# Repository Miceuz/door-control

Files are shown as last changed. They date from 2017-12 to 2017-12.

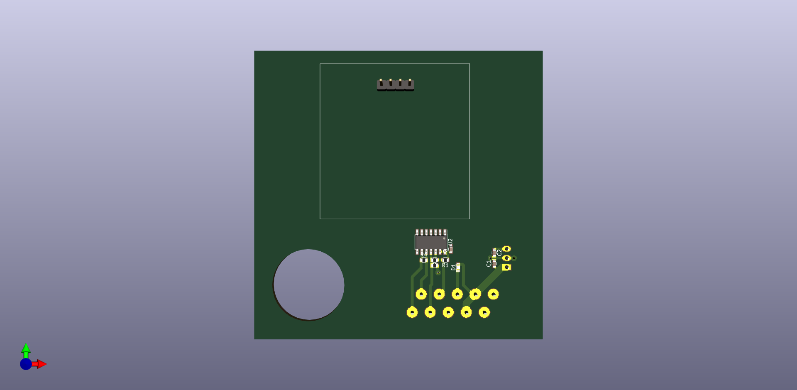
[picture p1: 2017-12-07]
scanner/scanner.png

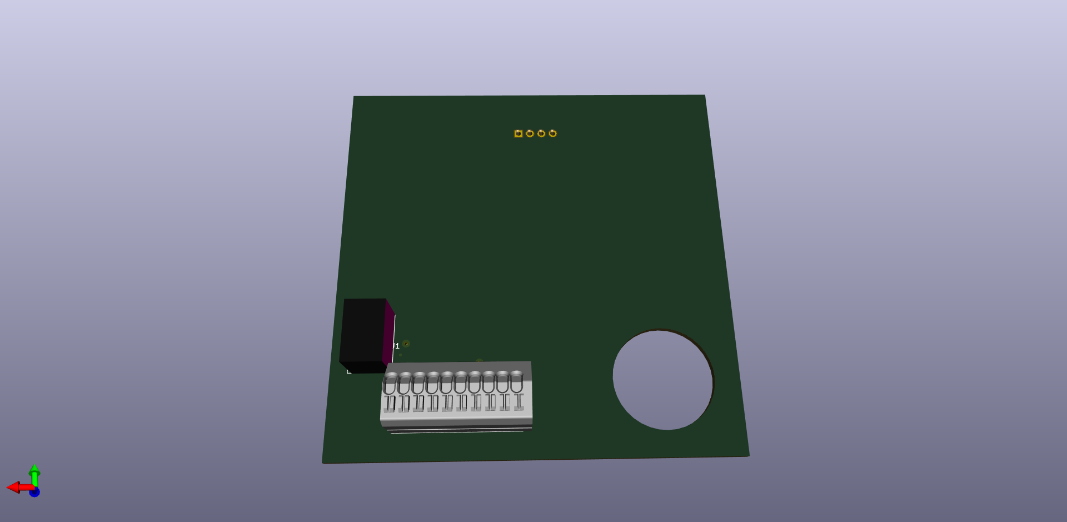
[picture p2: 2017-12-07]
scanner/scanner-back.png

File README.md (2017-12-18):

# door-control
An entrance to hackerspace control system

randominis minčių kratinys

 * Du maitinimo blokai - vienas, 5V maitina ESP32 plokštę, kitas, 12V - "purvinąją" pusę
 X* Iš 5V patempti už kojos tranzistorių ir sekti, ar yra 5V maitinimas
 X* Iš 12V per optoporą patempti tranzistorių ir sekti, ar yra 12V maitinimas
 X* RS485 izoliuotas per AD2482/AD2487
 * Išlituoti barrel lizdą įlituoti screw term
 http://www.mouser.com/pdfdocs/Bourns_RS485_AppNote.pdf

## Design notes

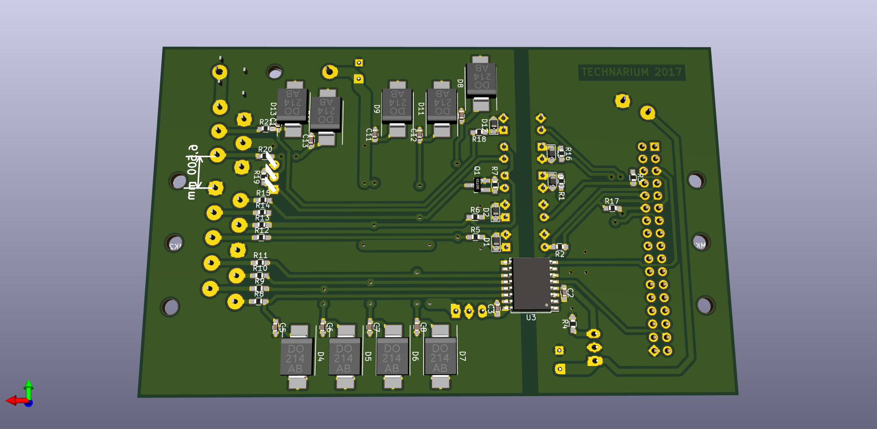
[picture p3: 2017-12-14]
controller2/controller2-bot.png

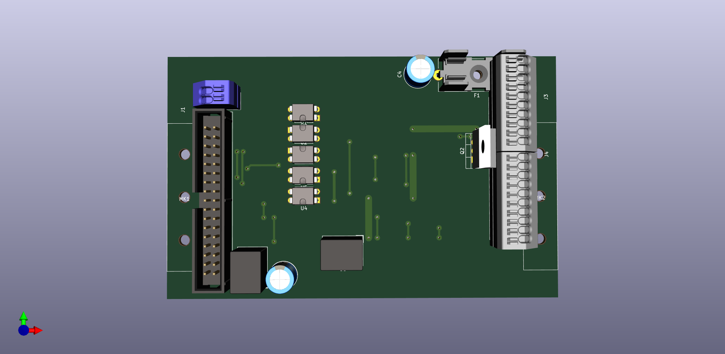
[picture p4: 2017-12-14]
controller2/controller2-top.png

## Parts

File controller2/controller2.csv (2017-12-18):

Reference | Quantity | Value | Footprint | PartNo | Manufacturer | Distributor
C1 C4 | 2 | CP | Capacitors_THT:CP_Radial_D8.0mm_P3.50mm | EEUFR1J151L | PANASONIC | 2760345
C10 C11 C12 C13 C2 C3 C5 C6 C7 C8 C9 | 11 | C | Capacitors_SMD:C_0603_HandSoldering |  |  | xxx
D11 D13 D14 D4 D5 D6 D7 D8 D9 | 9 | SMCJ24CA | Diodes_SMD:DO-214AB_Handsoldering | SMCJ24CA | LITTLEFUSE | 2762835
D1 D10 D12 D2 D3 | 5 | D_Small | Diodes_SMD:D_SOD-323_HandSoldering | 1N4148 | MULTICOMP | 1466524
F1 | 1 | Fuse | Fuse_Holders_and_Fuses:Fuseholder5x20_horiz_open_Schurter_0031_8201 | 0031.8201 | SCHURTER | 1162740
J1 | 1 | 5V_IN | door:TerminalBlock_WAGO-205_2pol | 250-402 | WAGO | 1891588
J2 | 1 | Conn_02x17_Odd_Even | Connectors_IDC:IDC-Header_2x17_Pitch2.54mm_Straight | T821134A1S100CEU | AMPHENOL | 2215313
J3 | 1 | Conn_01x06 | door:TerminalBlock_WAGO-205_10pol | 250-406 | WAGO | 1891592
J4 | 1 | Conn_01x10 | door:TerminalBlock_WAGO-205_10pol | 250-410 | WAGO | 1891594
Q1 | 1 | Q_NMOS_GSD | Housings_SOT-23_SOT-143_TSOT-6:SOT-23_Handsoldering | TN2404K-T1-GE3 | VISHAY | 2295731
Q2 | 1 | Q_NMOS_GSD | TO_SOT_Packages_THT:TO-220-3_Vertical | IRLZ14PBF | VISHAY | 8651370
R1 R16 R17 R18 R19 R2 R3 R4 R5 R6 R7 | 11 | R | Resistors_SMD:R_0603_HandSoldering |  |  | xxxx
R10 R11 R12 R13 R14 R15 R20 R21 R8 R9 | 10 | R_Small | Resistors_SMD:R_0603_HandSoldering | ERJPA3F10R0V | PANASONIC | 2335834
U1 U6 | 2 | R-78E3.3-0.5 | Converters_DCDC_ACDC:DCDC-Conv_RECOM_R-78E-0.5 | R-78E3.3-0.5 | RECOM | 2218602
U3 | 1 | ADM2482 | Housings_SOIC:SOIC-16W_7.5x10.3mm_Pitch1.27mm | ADM2487EBRWZ | ANALOG DEVICES | 2758680
U2 U4 U5 U7 U8 | 5 | TLP222 |  | TLP222A | TOSHIBA | 1761595

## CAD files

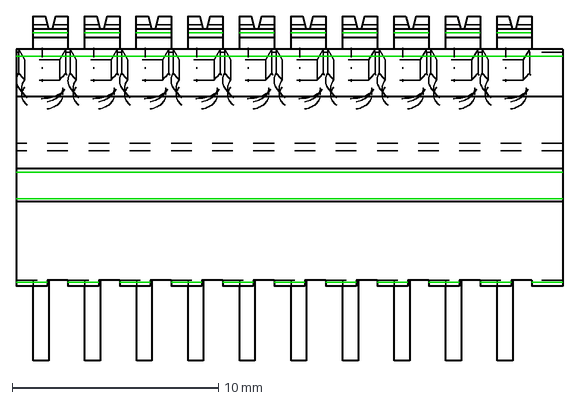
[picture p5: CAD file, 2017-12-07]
3d/250-410_left.dxf
26.5 x 16.7 mm

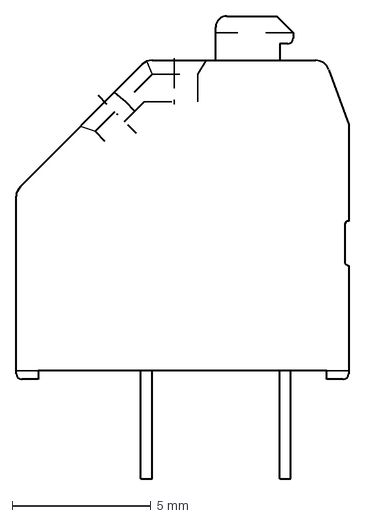
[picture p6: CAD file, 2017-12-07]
3d/250-410_back.dxf
12.0 x 16.7 mm

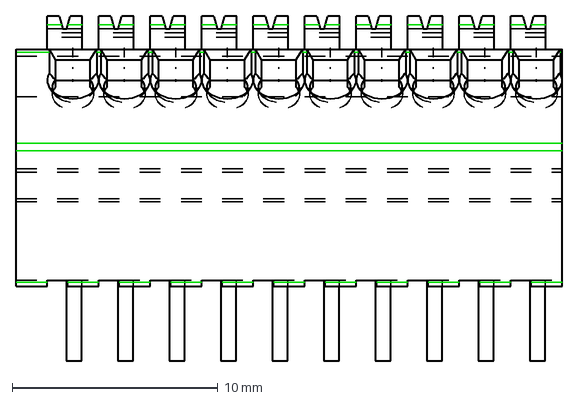
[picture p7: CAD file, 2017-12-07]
3d/250-410_right.dxf
26.6 x 16.7 mm

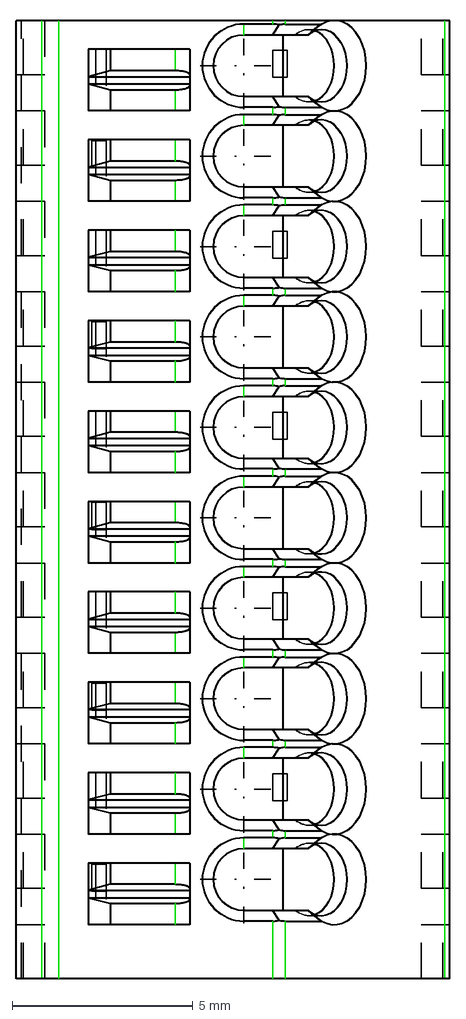
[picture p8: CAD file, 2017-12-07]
3d/250-410_top.dxf
12.0 x 26.6 mm

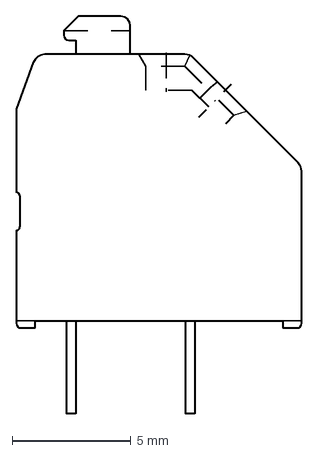
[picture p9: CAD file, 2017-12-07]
3d/250-410_front.dxf
12.0 x 16.7 mm

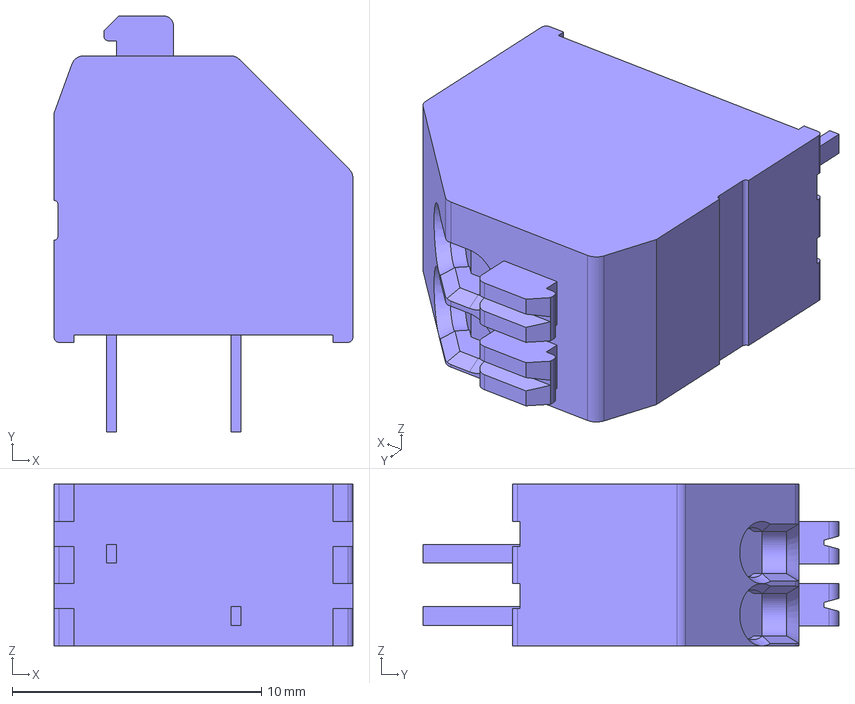
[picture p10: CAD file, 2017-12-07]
3d/250-402_000-006.stp
12.0 x 16.7 x 6.50 mm

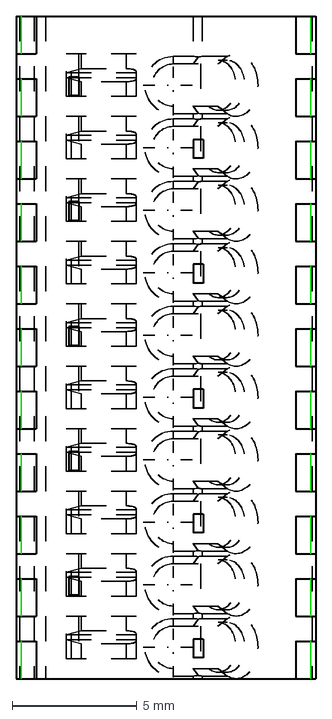
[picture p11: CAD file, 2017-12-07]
3d/250-410_bottom.dxf
12.0 x 26.5 mm

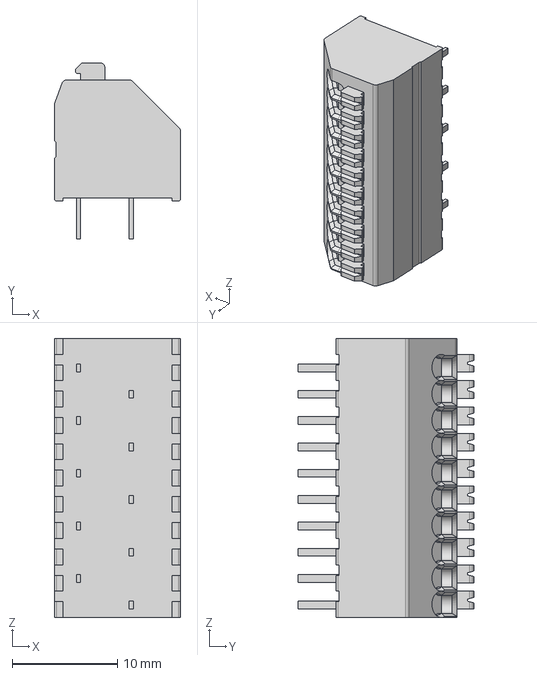
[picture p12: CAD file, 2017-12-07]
3d/250-410.stp
12.0 x 16.7 x 26.5 mm

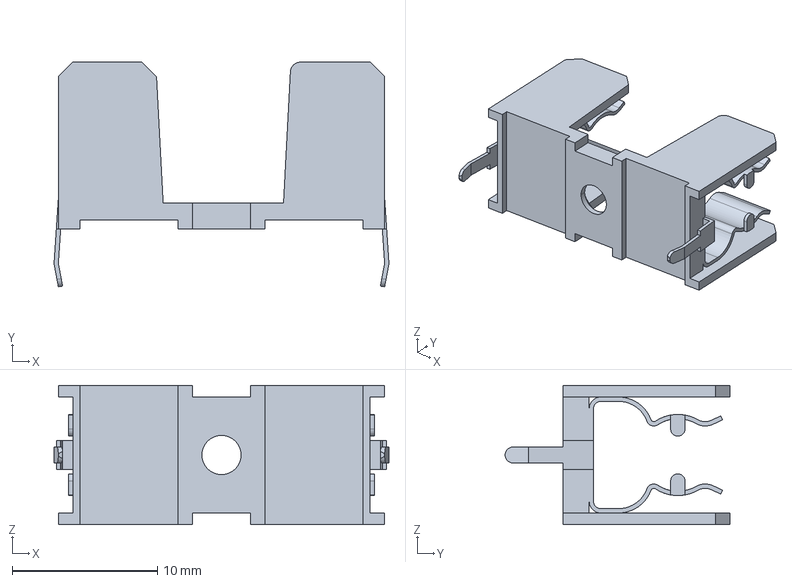
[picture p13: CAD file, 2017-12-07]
3d/31-8201.stp
23.1 x 15.5 x 9.60 mm

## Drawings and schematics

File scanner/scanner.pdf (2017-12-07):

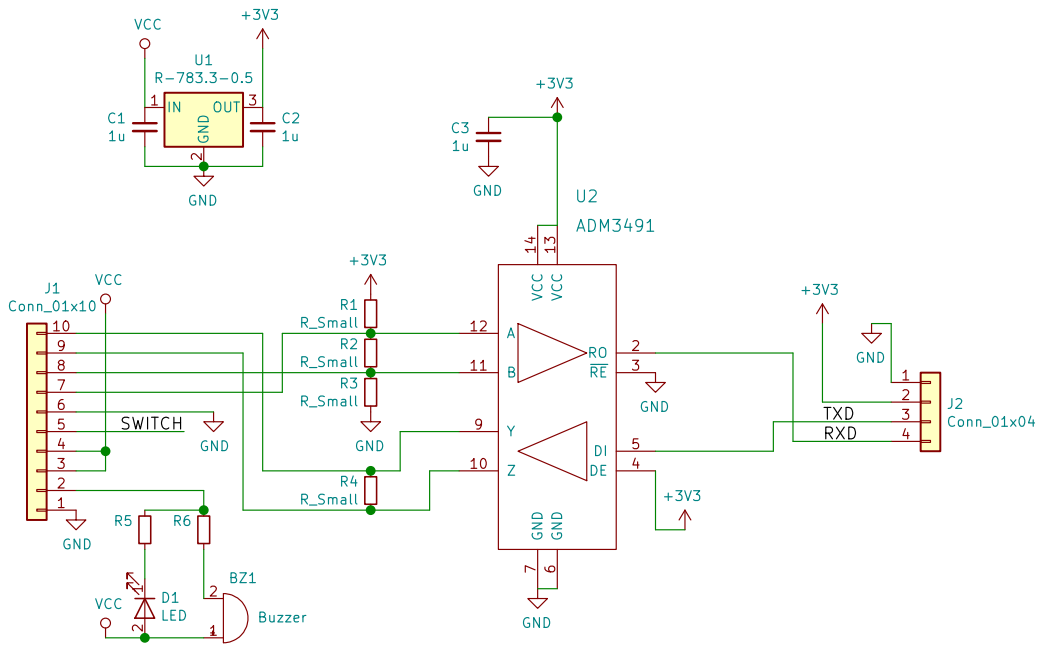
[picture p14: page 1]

RXD 4

Id: 1/1 Title: File: scanner.sch Sheet: / Albertas Micknas

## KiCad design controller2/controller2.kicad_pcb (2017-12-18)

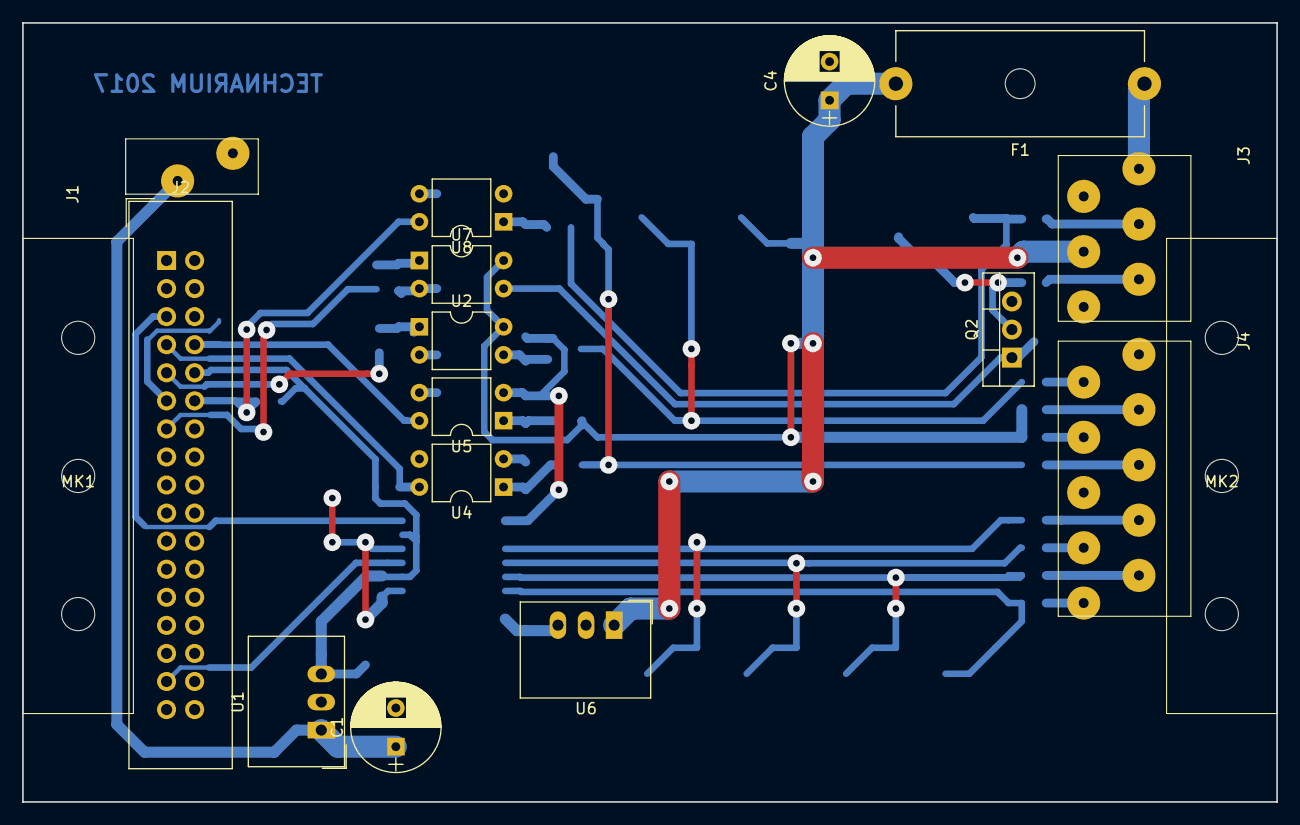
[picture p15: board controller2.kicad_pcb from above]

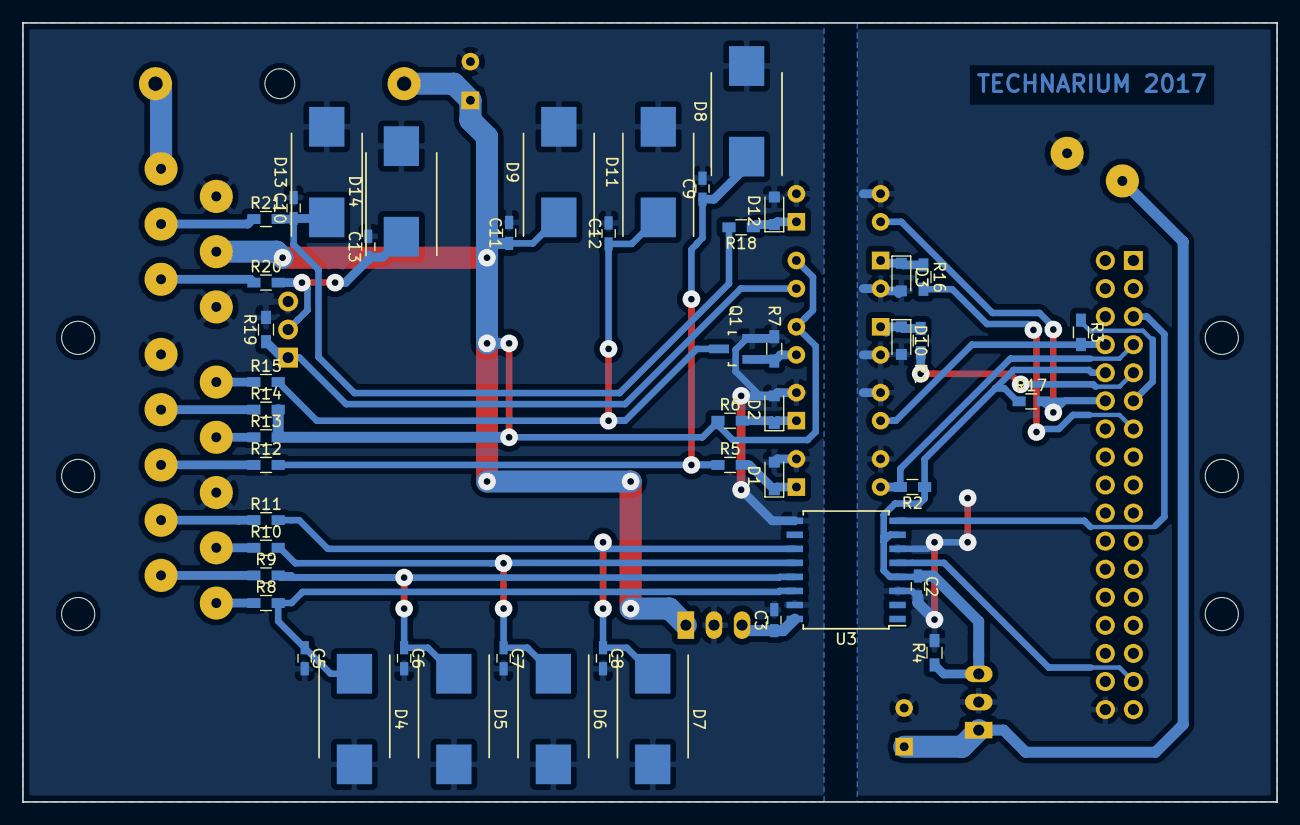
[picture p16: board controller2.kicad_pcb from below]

Board: 2 copper layers, 113.5 x 70.5 mm, 65 parts (48 on the bottom side), 40 nets.

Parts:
C1, C4: CP; CP_Radial_D8.0mm_P3.50mm
C2, C3, C5, C6, C7, C8, C9, C10, C11, C12, C13: C; C_0603_HandSoldering
D1, D2, D3, D10, D12: D_Small; D_SOD-323_HandSoldering
D4, D5, D6, D7, D8, D9, D11, D13, D14: SMCJ12CA; DO-214AB_Handsoldering
F1: Fuse; Fuseholder5x20_horiz_open_Schurter_0031_8201
J1: 5V_IN; TerminalBlock_WAGO-205_2pol
J2: Conn_02x17_Odd_Even; IDC-Header_2x17_Pitch2.54mm_Straight
J3: Conn_01x06; TerminalBlock_WAGO-205_10pol
J4: Conn_01x10; TerminalBlock_WAGO-205_10pol
MK1, MK2: Mounting_Hole; DIN_CLIP
Q1: Q_NMOS_GSD; SOT-23_Handsoldering
Q2: Q_NMOS_GSD; TO-220-3_Vertical
R1, R2, R3, R4, R5, R6, R7, R16, R17, R18, R19: R; R_0603_HandSoldering
R8, R9, R10, R11, R12, R13, R14, R15, R20, R21: R_Small; R_0603_HandSoldering
U1, U6: R-78E3.3-0.5; DCDC-Conv_RECOM_R-78E-0.5
U2, U4, U5, U7, U8: TLP222A; DIP-4_W7.62mm
U3: ADM2482; SOIC-16W_7.5x10.3mm_Pitch1.27mm

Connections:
+3V3: C2.1, J2.10, R2.1, R4.1, R17.1, U1.3, U3.4, U3.7
/AUX_IN: C10.1, D13.1, R18.2, R21.2
/AUX_IN_ISO: J2.12, R17.2, U8.4
/AUX_OUT: C13.1, D14.1, Q2.2, R20.2
/AUX_OUT_ISO: J2.13, R16.2
/BUZZ_ISO: J2.9, R1.2
/BUZZ_LED: C12.1, D11.1, Q1.3, R15.2
/RxD: J2.31, U3.5
/SWITCH: C9.1, D8.1, R5.1, R12.2
/TxD: J2.5, U3.8
/VCC_TEST: J2.11, R3.1
/~SWITCH_ISO: J2.7, R2.2, U4.4
/~VCC_GOOD: J2.8, R3.2, U5.4
GND: C1.2, C2.2, D3.2, D10.2, J1.2, J2.34, R4.2, U1.2, U2.2, U3.3, U3.6, U4.3, U5.3, U7.2, U8.3
GNDD: C3.2, C4.2, C5.2, C6.2, C7.2, C8.2, C9.2, C10.2, C11.2, C12.2, C13.2, D1.2, D2.2, D4.2, D5.2, D6.2, D7.2, D8.2, D9.2, D11.2, D12.2, D13.2, D14.2, J3.2, J3.6, J4.1, J4.6, Q1.2, Q2.3, R7.2, R19.2, U3.9, U3.15, U4.2, U5.2, U6.2, U8.2
unnamed: C1.1, J1.1, U1.1
unnamed: C3.1, U3.16, U6.3
unnamed: C5.1, D4.1, R8.2, U3.14
unnamed: C6.1, D5.1, R9.2, U3.13
unnamed: C7.1, D6.1, R10.2, U3.12
unnamed: C8.1, D7.1, R11.2, U3.11
unnamed: D1.1, R5.2, U4.1
unnamed: D2.1, R6.2, U5.1
unnamed: D3.1, R16.1, U7.1
unnamed: D10.1, R1.1, U2.1
unnamed: D12.1, R18.1, U8.1
unnamed: F1.1, J3.1
unnamed: J3.3, R21.1
unnamed: J3.5, R20.1
unnamed: J4.2, R15.1
unnamed: J4.3, R14.1
unnamed: J4.4, R13.1
unnamed: J4.5, R12.1
unnamed: J4.7, R11.1
unnamed: J4.8, R10.1
unnamed: J4.9, R9.1
unnamed: J4.10, R8.1
unnamed: Q1.1, R7.1, U2.3
unnamed: Q2.1, R19.1, U7.3
VCC: C4.1, C11.1, D9.1, F1.2, J3.4, R6.1, R13.2, R14.2, U2.4, U6.1, U7.4

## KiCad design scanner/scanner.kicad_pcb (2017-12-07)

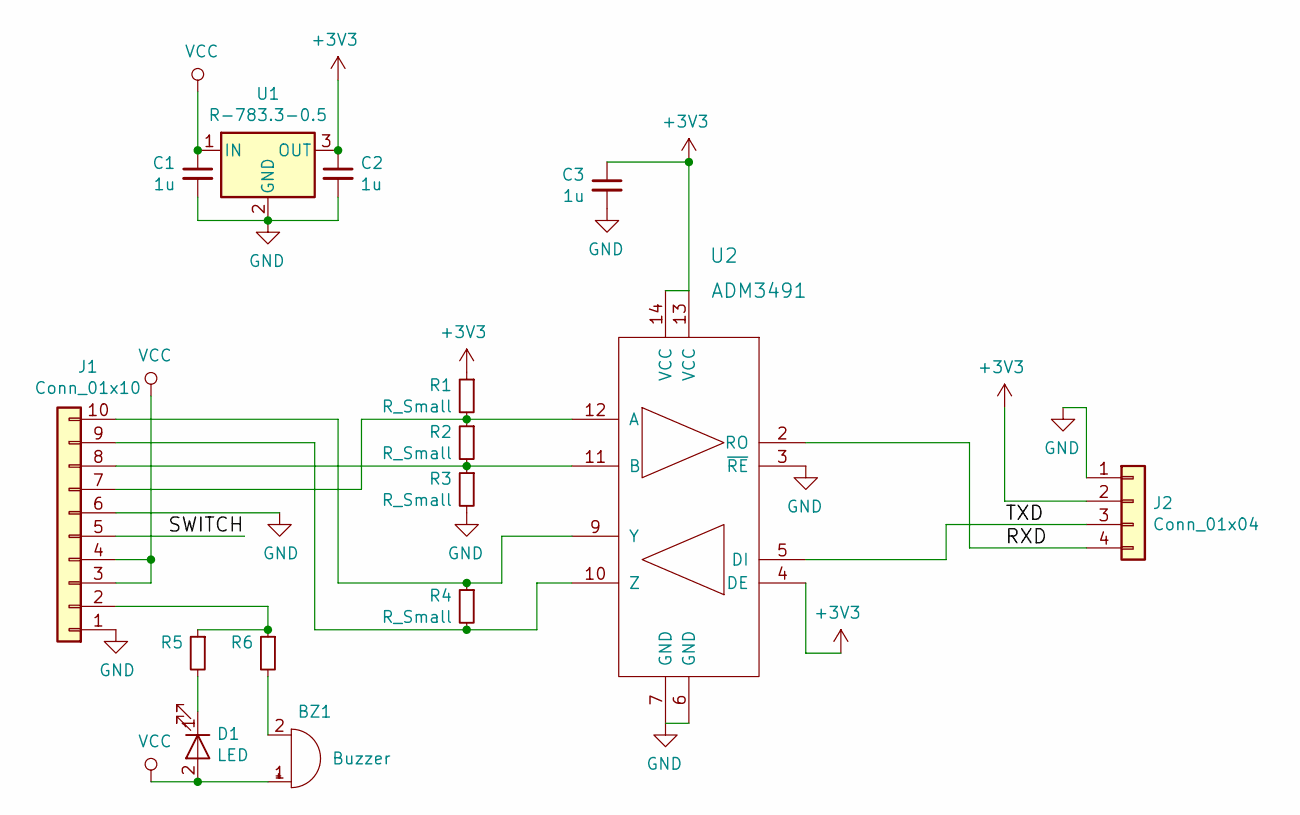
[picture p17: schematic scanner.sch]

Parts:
BZ1: Buzzer; Buzzer_12x9.5RM7.6; PartNo AI-1440-TWT-12V-R
C1, C2, C3: 1u; C_0603; PartNo ?
D1: LED; LED_0603; PartNo ?
J1: Conn_01x10; TerminalBlock_WAGO-804_RM5mm_10pol; PartNo 250-410
J2: Conn_01x04; Pin_Header_Straight_1x04_Pitch2.54mm; PartNo ?
R1, R2, R3, R4: R_Small; R_0603; PartNo ?
R5, R6: R_0603; PartNo ?
U1: R-783.3-0.5; DCDC-Conv_RECOM_R-78E-0.5; PartNo R-78E3.3-0.5
U2: ADM3491; SOIC-14_3.9x8.7mm_Pitch1.27mm; PartNo ADM3491EARZ

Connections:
+3V3: C2.1, C3.1, J2.2, R1.1, U1.3 (OUT), U2.4 (DE), U2.8 (NC), U2.13 (VCC), U2.14 (VCC)
/RXD: J2.4, U2.2 (RO)
/SWITCH: J1.5
/TXD: J2.3, U2.5 (DI)
GND: C1.2, C2.2, C3.2, J1.1, J1.6, J2.1, R3.2, U1.2 (GND), U2.3 (~RE), U2.6 (GND), U2.7 (GND)
unnamed: BZ1.2 (+), R6.2
unnamed: D1.1 (K), R5.2
unnamed: J1.2, R5.1, R6.1
unnamed: J1.7, R1.2, R2.1, U2.12 (A)
unnamed: J1.8, R2.2, R3.1, U2.11 (B)
unnamed: J1.9, R4.2, U2.10 (Z)
unnamed: J1.10, R4.1, U2.9 (Y)
VCC: BZ1.1 (-), C1.1, D1.2 (A), J1.3, J1.4, U1.1 (IN)

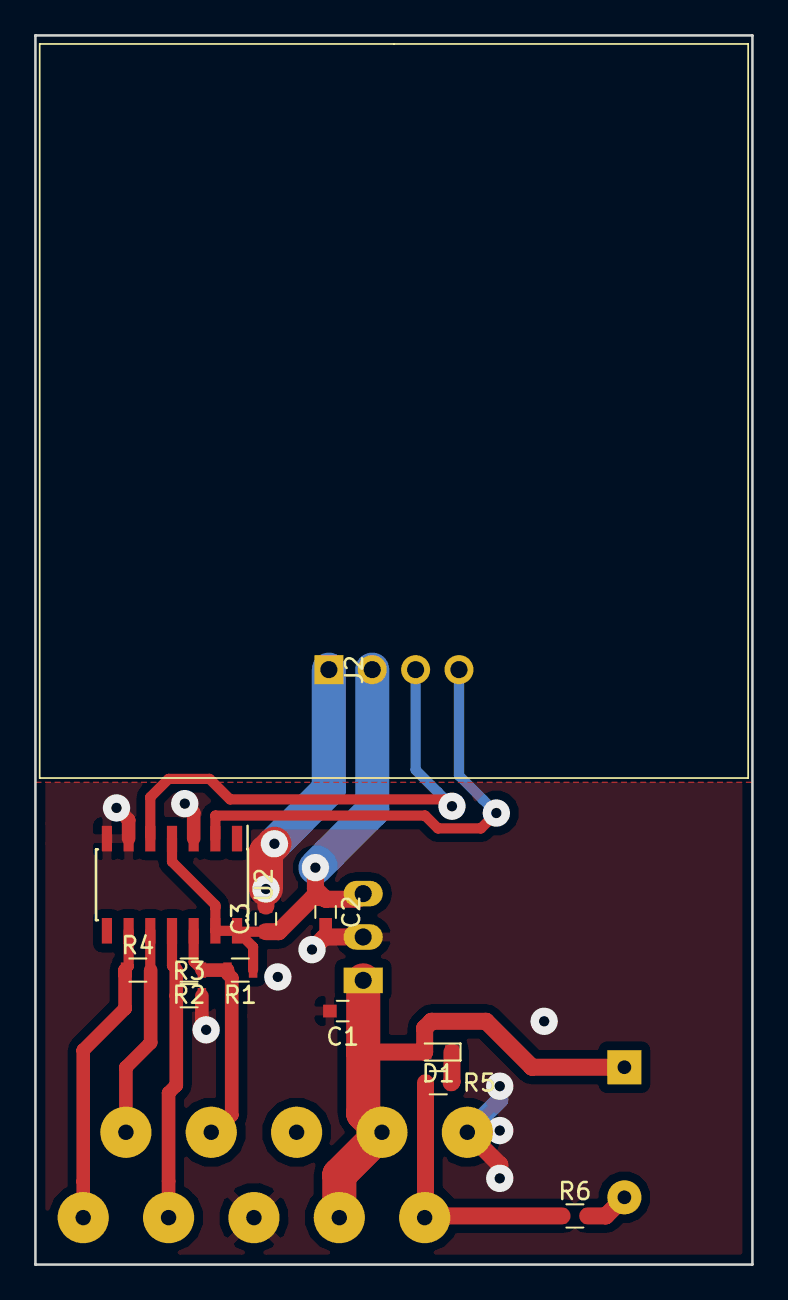
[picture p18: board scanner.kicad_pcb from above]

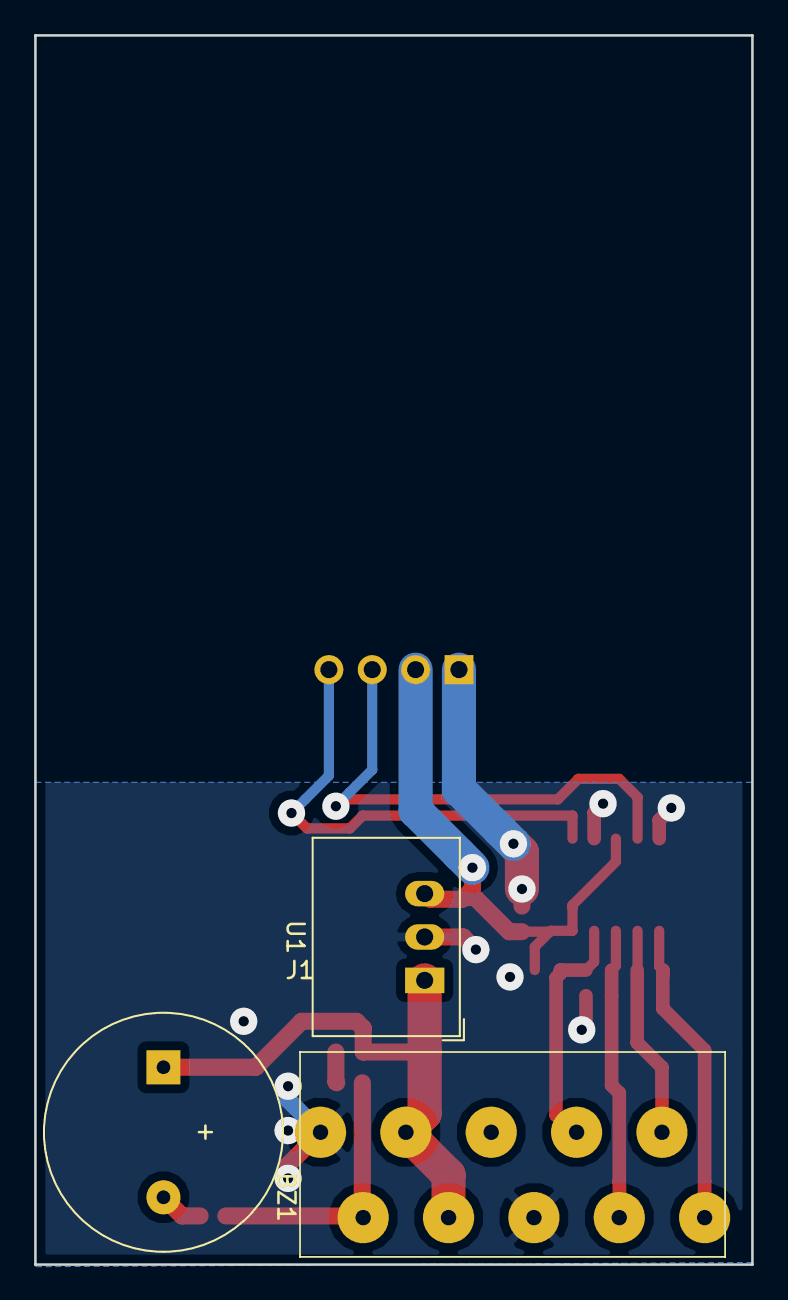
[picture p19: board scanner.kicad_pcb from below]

Board: 2 copper layers, 42.0 x 72.0 mm, 15 parts (3 on the bottom side), 12 nets.

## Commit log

2017-01-06 Initial commit. Basic schematics of controller are done
    [ASMBOT-ORANGE_PI-Zero-V1_1.dwg, ASMTOP-ORANGE_PI-Zero-V1_1.dwg, DoorCtrl.kicad_pcb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]
2017-01-06 Move controller related stuff to a separate folder
    [DoorCtrl.kicad_pcb, DoorCtrl.sch, dcdc.sch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]
2017-12-07 Add the most recent stuff - scanner and the new interface board
    [controller2.kicad_pcb, controller2.sch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]
2017-12-07 Add some 3d models
    [250-402_000-006.stp, 250-410.stp, 250-410_back.dxf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]
2017-12-14 No commit no cry. Controller IO isolation board is ready for manufacturing
    [controller2.csv, controller2.kicad_pcb, controller2.sch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]
2017-12-18 Remove some old stuff
    [ASMBOT-ORANGE_PI-Zero-V1_1.dwg, ASMTOP-ORANGE_PI-Zero-V1_1.dwg, DoorCtrl.kicad_pcb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]
